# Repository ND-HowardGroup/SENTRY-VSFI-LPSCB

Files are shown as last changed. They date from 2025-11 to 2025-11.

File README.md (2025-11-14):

# SENTRY-VSFI-LPSCB
Schematics and PCB Design for GPS and LoRa enabled low-power sensor communications board (LPSCB).

Developed as part of the [DHS SENTRY Center of Excellence](https://sentry.northeastern.edu/), these boards
and prototype development boards for integrating GPS, LoRa, and I2C connected sensors. This is the first generation
device for preliminary testing and education purposes.

These boards can be programmed over USB as if they are a Raspberry Pi Pico 1 (RP2040) following Raspberry Pi's
[standard documentation](https://www.raspberrypi.com/documentation/microcontrollers/pico-series.html).

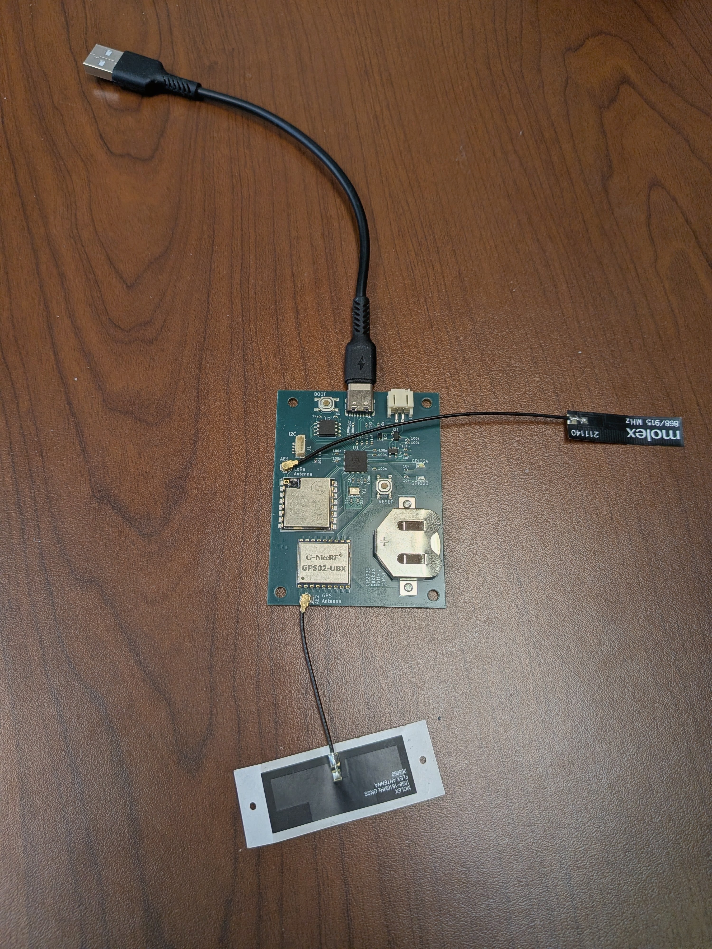
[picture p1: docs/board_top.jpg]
Photo of the top-side of an assembled board.


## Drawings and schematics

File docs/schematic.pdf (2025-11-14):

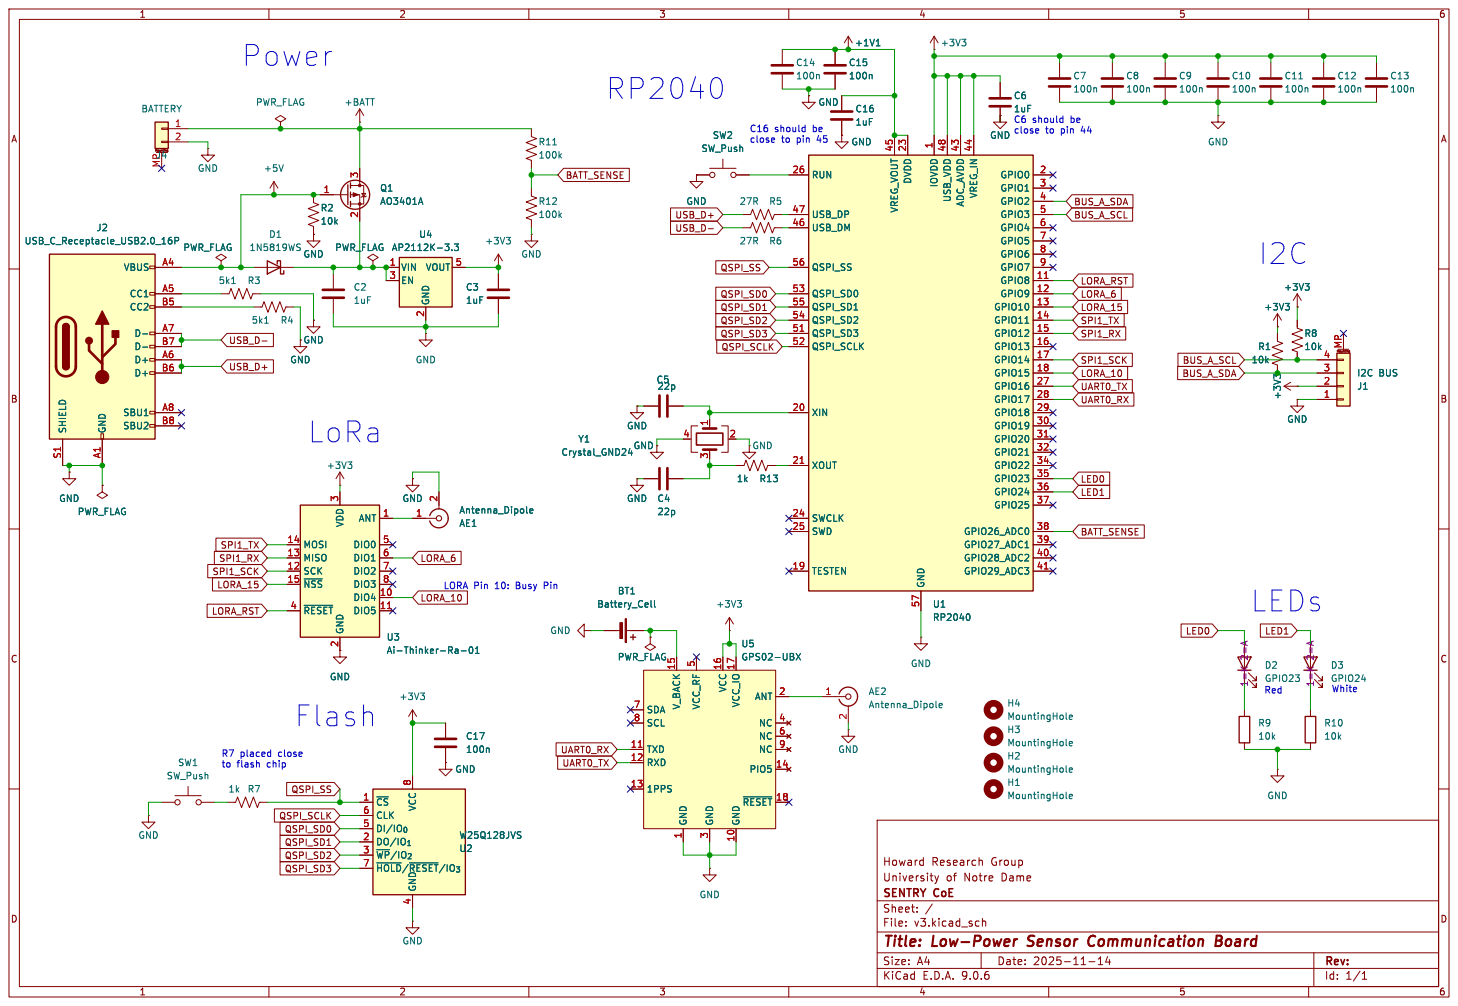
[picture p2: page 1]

close to pin 44 Flash

LORA Pin 10: Busy Pin R7 placed close

3 VCC 16 VCC_IO 17 GND 10 ANT 2 NC 4 NC 6 NC 9 PIO5 14 ~{RESET} 18 U5 PWR_FLAG GPS02-UBX D3 GPIO24 1=K 2=A R10

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

SDA 7 SCL 8 TXD 11 RXD 12

H4 MountingHole H3 MountingHole H2 MountingHole H1 MountingHole

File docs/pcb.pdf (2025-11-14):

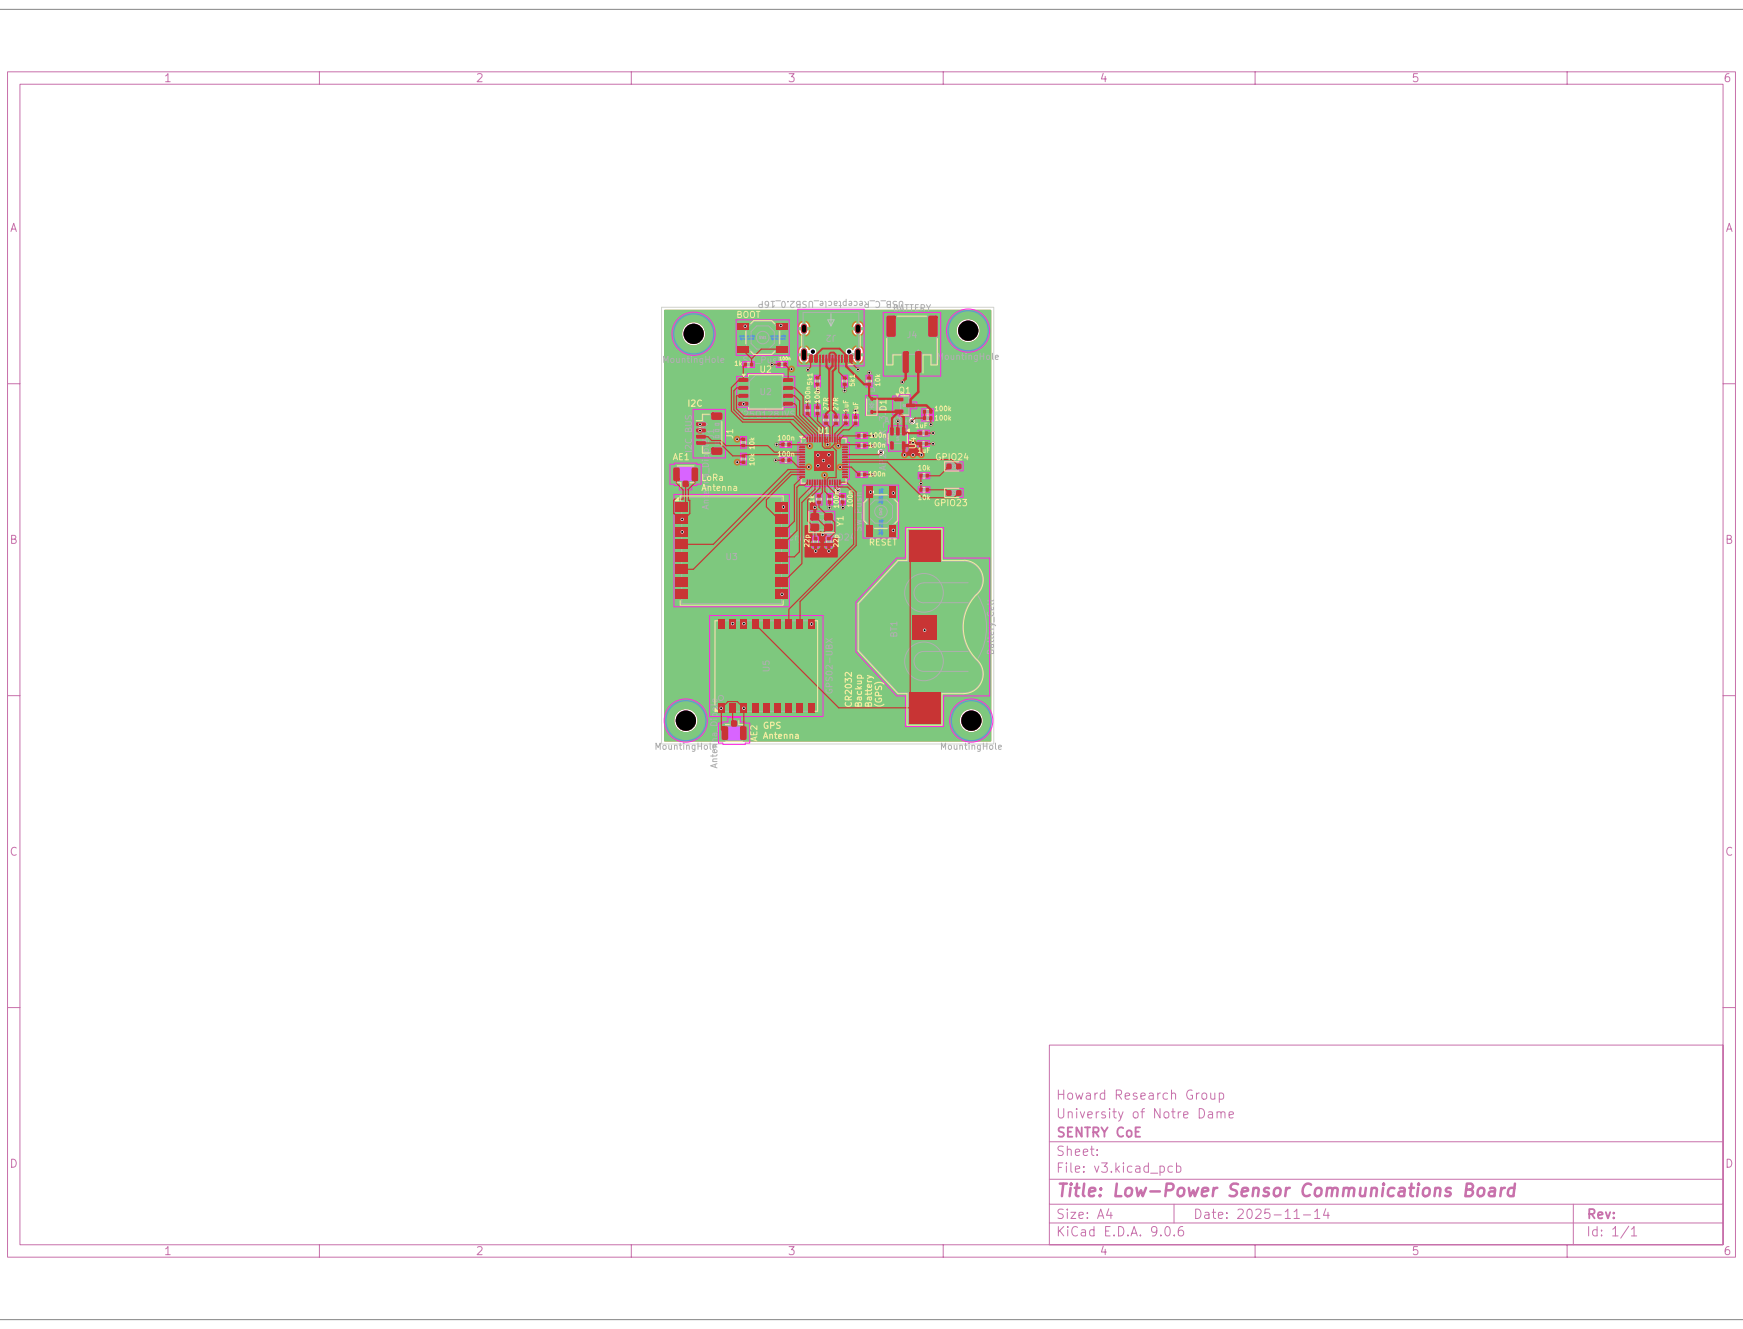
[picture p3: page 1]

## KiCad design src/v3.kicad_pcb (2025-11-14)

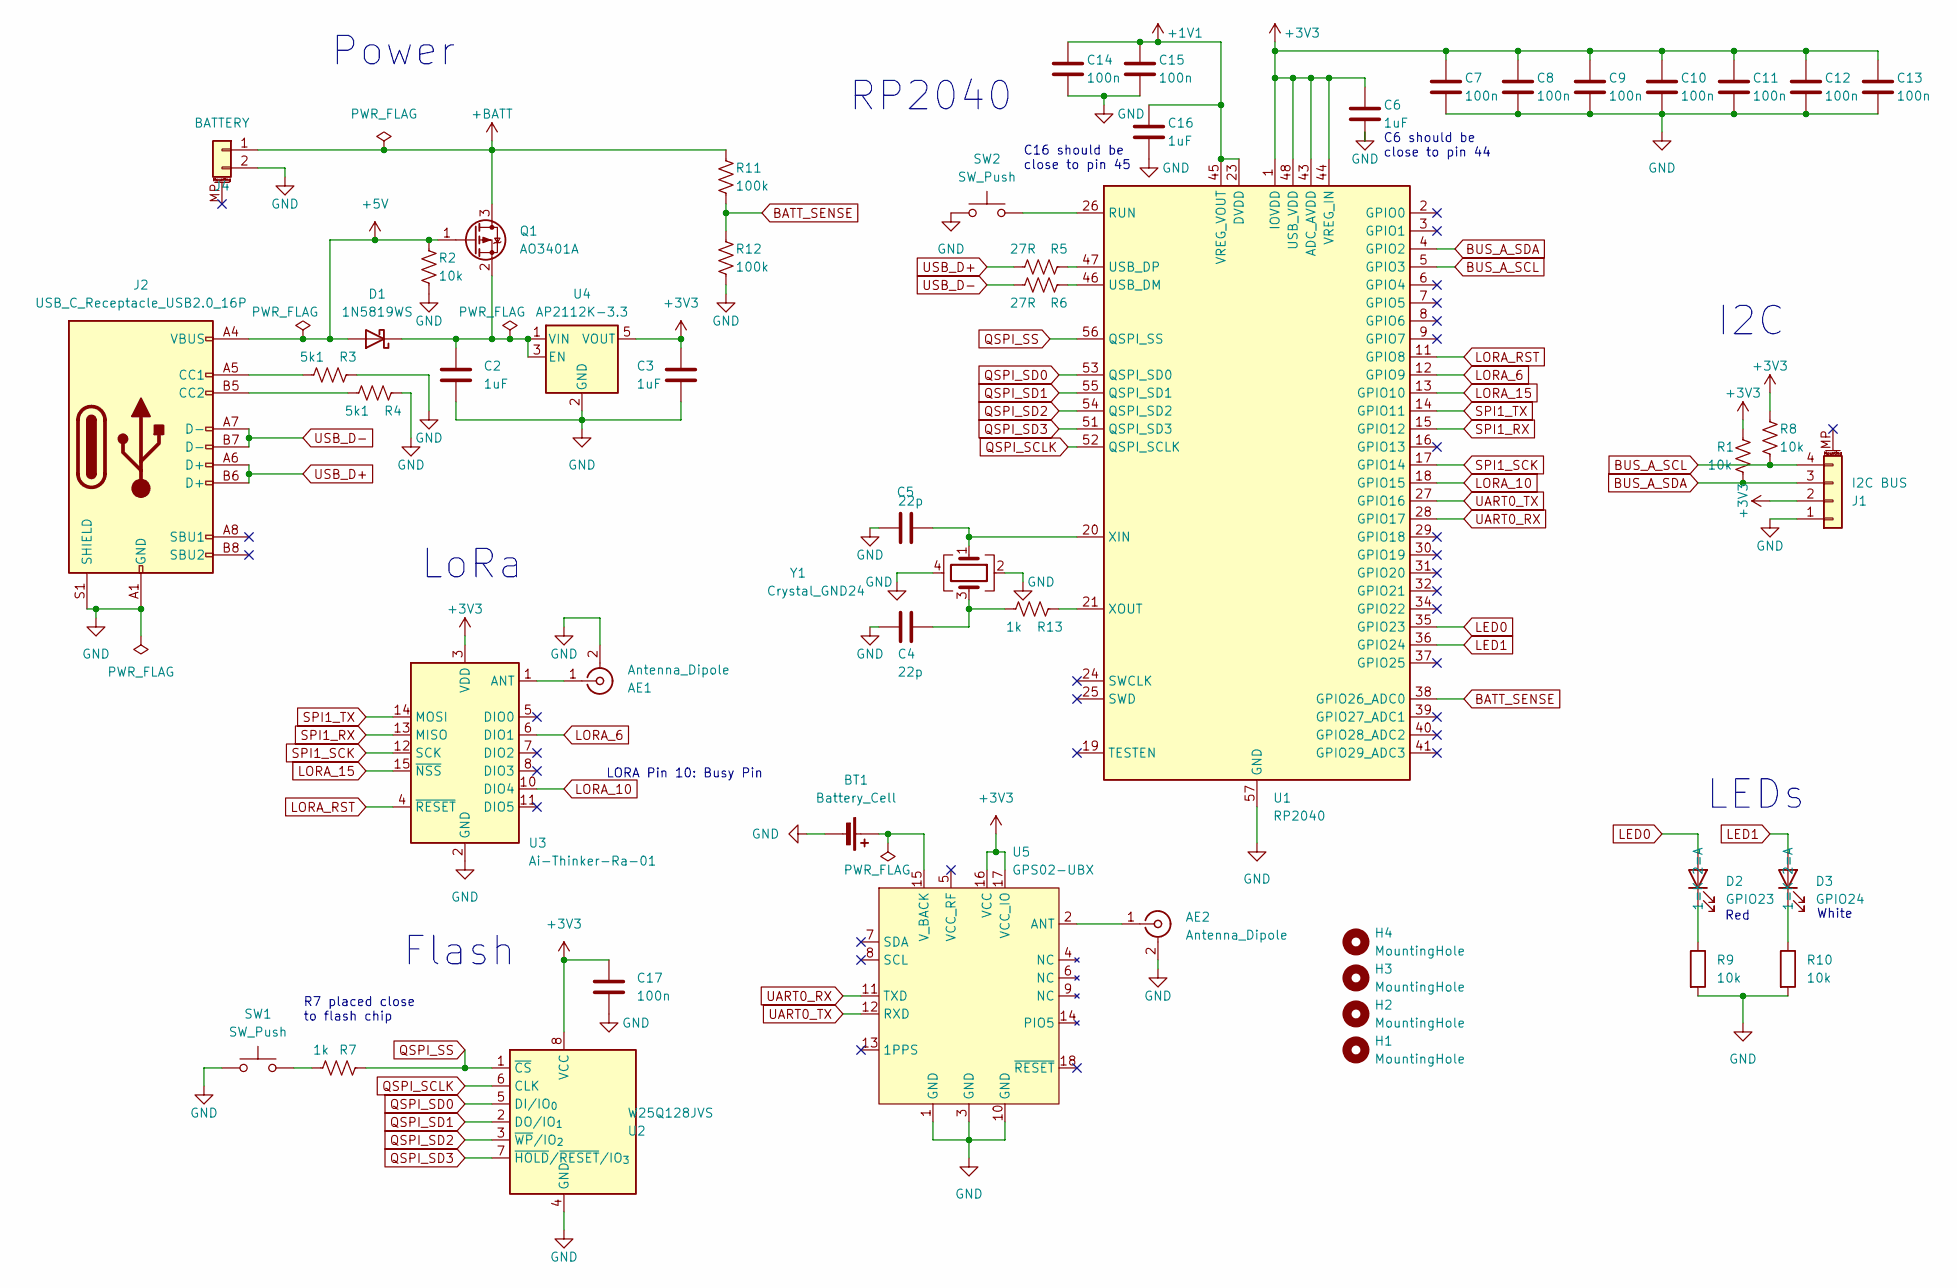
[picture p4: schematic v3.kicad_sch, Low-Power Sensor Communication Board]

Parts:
AE1, AE2: Antenna_Dipole; U.FL_Hirose_U.FL-R-SMT-1_Vertical; LCSC C88374
BT1: Battery_Cell; BatteryHolder_Multicomp_BC-2001_1x2032; LCSC C964829
C2, C3, C6, C16: 1uF; C_0402_1005Metric; LCSC C52923
C4, C5: 22p; C_0402_1005Metric; LCSC C1555
C7, C8, C9, C10, C11, C12, C13, C14, C15, C17: 100n; C_0402_1005Metric; LCSC C1525
D1: 1N5819WS; D_SOD-323; LCSC C191023
D2: GPIO23; LED_0603_1608Metric; LCSC C2286
D3: GPIO24; LED_0603_1608Metric; LCSC C2290
H1, H2, H3, H4: MountingHole; MountingHole_3.2mm_M3
J1: I2C BUS; JST_SH_BM04B-SRSS-TB_1x04-1MP_P1.00mm_Vertical; LCSC C160390
J2: USB_C_Receptacle_USB2.0_16P; USB_C_Receptacle_HCTL_HC-TYPE-C-16P-01A; LCSC C2894897
J4: BATTERY; JST_PH_S2B-PH-SM4-TB_1x02-1MP_P2.00mm_Horizontal; LCSC C295747
Q1: AO3401A; SOT-23; LCSC C15127
R1, R2, R8, R9, R10: 10k; R_0402_1005Metric; LCSC C25744
R3, R4: 5k1; R_0402_1005Metric; LCSC C25905
R5, R6: 27R; R_0402_1005Metric; LCSC C25100
R7, R13: 1k; R_0402_1005Metric; LCSC C11702
R11, R12: 100k; R_0402_1005Metric; LCSC C25741
SW1, SW2: SW_Push; SW_SPST_SKQG_WithStem; LCSC C318884
U1: RP2040; QFN-56-1EP_7x7mm_P0.4mm_EP3.2x3.2mm; LCSC C2040
U2: W25Q128JVS; SOIC-8_5.3x5.3mm_P1.27mm; LCSC C97521
U3: Ai-Thinker-Ra-01; Ai-Thinker-Ra-01-LoRa; LCSC C2764087
U4: AP2112K-3.3; SOT-23-5; LCSC C51118
U5: GPS02-UBX; QFN-20_14.5x16.45_Pitch1.8mm; LCSC C5356636
Y1: Crystal_GND24; Crystal_SMD_3225-4Pin_3.2x2.5mm; LCSC C9002

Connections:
+1V1: C14.1, C15.1, C16.1, U1.23 (DVDD), U1.45 (VREG_VOUT), U1.50 (DVDD)
+3V3: C3.1, C6.1, C7.1, C8.1, C9.1, C10.1, C11.1, C12.1, C13.1, C17.1, J1.2, R1.1, R8.1, U1.1 (IOVDD), U1.10 (IOVDD), U1.22 (IOVDD), U1.33 (IOVDD), U1.42 (IOVDD), U1.43 (ADC_AVDD), U1.44 (VREG_IN), U1.48 (USB_VDD), U1.49 (IOVDD), U2.8 (VCC), U3.3 (VDD), U4.5 (VOUT), U5.16 (VCC), U5.17 (VCC_IO)
+5V: D1.2 (A), J2.A4 (VBUS), J2.A9 (VBUS), J2.B4 (VBUS), J2.B9 (VBUS), Q1.1 (G), R2.1
+BATT: J4.1, Q1.3 (D), R11.1
BATT_SENSE: R11.2, R12.1, U1.38 (GPIO26_ADC0)
BUS_A_SCL: J1.4, R8.2, U1.5 (GPIO3)
BUS_A_SDA: J1.3, R1.2, U1.4 (GPIO2)
GND: AE1.2 (Ext), AE2.2 (Ext), BT1.2 (-), C2.2, C3.2, C4.2, C5.1, C6.2, C7.2, C8.2, C9.2, C10.2, C11.2, C12.2, C13.2, C14.2, C15.2, C16.2, C17.2, J1.1, J2.A1 (GND), J2.A12 (GND), J2.B1 (GND), J2.B12 (GND), J2.S1 (SHIELD), J4.2, R2.2, R3.1, R4.2, R9.2, R10.2, R12.2, SW1.1, SW2.1, U1.57 (GND), U2.4 (GND), U3.2 (GND), U3.9 (GND), U3.16 (GND), U4.2 (GND), U5.1 (GND), U5.3 (GND), U5.10 (GND), Y1.2, Y1.4
LED0: D2.2 (A), U1.35 (GPIO23)
LED1: D3.2 (A), U1.36 (GPIO24)
LORA_6: U1.12 (GPIO9), U3.6 (DIO1)
LORA_10: U1.18 (GPIO15), U3.10 (DIO4)
LORA_15: U1.13 (GPIO10), U3.15 (~NSS)
LORA_RST: U1.11 (GPIO8), U3.4 (~RESET)
unnamed: AE1.1 (In), U3.1 (ANT)
unnamed: AE2.1 (In), U5.2 (ANT)
unnamed: BT1.1 (+), U5.15 (V_BACK)
unnamed: C4.1, R13.2, Y1.3
unnamed: C2.1, D1.1 (K), Q1.2 (S), U4.1 (VIN), U4.3 (EN)
unnamed: D2.1 (K), R9.1
unnamed: D3.1 (K), R10.1
unnamed: J2.A5 (CC1), R3.2
unnamed: J2.B5 (CC2), R4.1
unnamed: R7.1, SW1.2
unnamed: SW2.2, U1.26 (RUN)
unnamed: R6.1, U1.46 (USB_DM)
unnamed: R5.1, U1.47 (USB_DP)
unnamed: C5.2, U1.20 (XIN), Y1.1
unnamed: R13.1, U1.21 (XOUT)
QSPI_SCLK: U1.52 (QSPI_SCLK), U2.6 (CLK)
QSPI_SD0: U1.53 (QSPI_SD0), U2.5 (DI/IO_{0})
QSPI_SD1: U1.55 (QSPI_SD1), U2.2 (DO/IO_{1})
QSPI_SD2: U1.54 (QSPI_SD2), U2.3 (~WP/IO_{2})
QSPI_SD3: U1.51 (QSPI_SD3), U2.7 (~HOLD/~RESET/IO_{3})
QSPI_SS: R7.2, U1.56 (QSPI_SS), U2.1 (~CS)
SPI1_RX: U1.15 (GPIO12), U3.13 (MISO)
SPI1_SCK: U1.17 (GPIO14), U3.12 (SCK)
SPI1_TX: U1.14 (GPIO11), U3.14 (MOSI)
UART0_RX: U1.28 (GPIO17), U5.11 (TXD)
UART0_TX: U1.27 (GPIO16), U5.12 (RXD)
USB_D+: J2.A6 (D+), J2.B6 (D+), R5.2
USB_D-: J2.A7 (D-), J2.B7 (D-), R6.2

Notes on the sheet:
I2C
R7 placed close to flash chip
LORA Pin 10: Busy Pin
RP2040
C6 should be close to pin 44
C16 should be close to pin 45
LEDs
White
Power
Red
LoRa
Flash

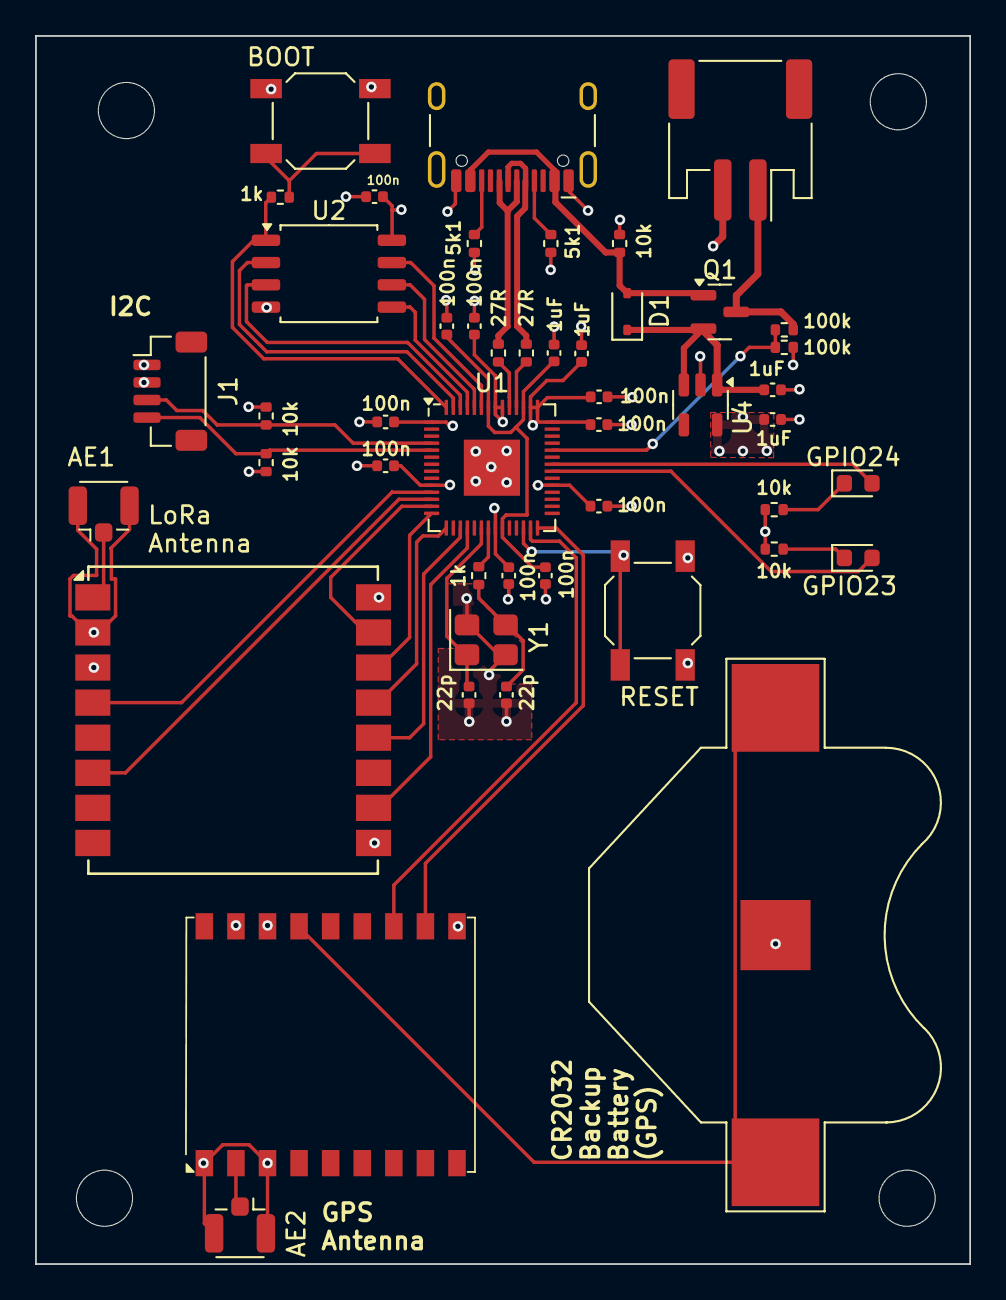
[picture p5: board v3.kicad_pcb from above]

Board: 4 copper layers, 53.3 x 70.0 mm, 51 parts (0 on the bottom side), 42 nets.
